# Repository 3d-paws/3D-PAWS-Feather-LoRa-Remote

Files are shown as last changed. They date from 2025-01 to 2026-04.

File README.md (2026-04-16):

# 3D-PAWS-Feather-LoRa-Remote

Last Updated: 2025-10-08

## Description

This software is supported on a Adafruit Feather LoRa board. It provides full weather station features. It uses LoRa (not LoRaWAN) to transmit observations to a receiving station for relay. Currently that is a Particle Full Station with Adafruit LoRa RFM95 module. Future plan is to also support for a RaspberryPI as a receiver and relay.

### Normal Main Loop operation
Normally the unit is in low power sleep mode. If a rain tip occurs, we wake up increment the tip count in the interrupt handler. Wakeup from sleep occures on configation settings of (5,6,10,15,20,30 minute) hourly periods. Actually wakeup is 1 minute prior from one of these periods. If Wind, Distance or Air Quality is configured. This allows time for samples to be taken for those observations where it is required. After observations have been made, they are transmitted in one or more LoRa messages. Then time to next observation is determined and we go into low power mode for this duration.

#### Things to Note

- The same sensors the Particle Full Station supports are supported by the Feather LoRaRemote. See [Particle Full Station Documentation](https://github.com/3d-paws/3D-PAWS-Particle-FullStation/blob/master/README.md) for sensors information.
- LoRa transmission are AES128 bit encrypted. The settings must match those on the receiving site.
- When we transmit we are sending to a LoRa gateway id 1. The receiving site must be addressed with the same id.
- Our LoRa id is set to match the Chords site these observations are destined for. The webhook at on the Particle Console will use this id to direct the observation to the logging site.
- Observation data are transmitted in JSON format. In that a unique device is is transmitted with every transmission. Example "devid":"548fa41ef43ee791". This can used if Chords is no longer the end logging site.
- At startup and every 24 hours after a INFO message is sent. These will be multiple LoRa messages. This is do to the LoRa message length constraint. INFO provides information on the station's configuration. File INFO.TXT on the SD card will be maintained with the most current information. Below is an example.

<div style="overflow:auto; white-space:pre; font-family: monospace; font-size: 8px; line-height: 1.5; height: 100px; border: 1px solid black; padding: 10px;">

```
{"at":"2026-04-13T15:58:08","id":2,"devid":"548fa41ef43ee791","mtype":"IF","ver":"FLR-260412","bv":4.28,"hth":1,"obsi":"15m","obsti":"15m","t2nt":"52s","elev":0,"rtro":"0:00","lora":"72,23,915MHz,OK","devs":"eeprom,dsmux,sd,gps","gps":{"lat":40.096000,"lon":-105.088398,"alt":1560.100000,"sat":11,"hdop":1.000000,"on":0}"sensors":"BMX1(BMP390),BMX2(BMP280),MCP1,SHT45(44),SHT31(45),HDC302X(46),BMP581(47),AS5600,WS(A2),HI,WBT,WBGT WO/GLOBE"}
```

</div>

- A I2C mux is supported for multiple Tinovi Soil Moisture sensors.
- SDU Boot is supported after the first code install via USB port is performed. After which to install new code you can add file UPDATE.BIN on the SD card. UPDATE.BIN is removed as part up the update process.

### Air Quality Sensor PM25AQI
- Air Quality Sensor PM25AQI must be connected to mux port 7. And feather pin D6 must be connected to PM25AQI pin SET. This turns on and off the PM25AQI fan and laser. The mux is needed to isolate the PM25AQI's I2C channel. The PM25AQI hold the I2C buss when powered down. Interfering with other I2C devices.
- Air Quality Sensor PM25AQI should be powered by the 5V VBUS pin. We have seen issues multiple i2c devices and the AQS.
- Adding a Air Quality Sensor PM25AQI has added instability with random lockup during sample taking.

### LoRa Antenna Length
The recommended antenna wire lengths for Adafruit LoRa Feather boards are frequency-dependent quarter-wave whip antennas:
- For 433 MHz, the antenna length should be 6.5 inches (16.5 cm).
- For 868 MHz, the antenna length should be 3.25 inches (8.2 cm).
- For 915 MHz, the antenna length should be 3 inches (7.8 cm).

## READMEs
### [Configuration File Example](docs/Configuration.md)
### [GPS Module](docs/GPSModule.md)
### [Pin Mappings](docs/PinMappings.md)

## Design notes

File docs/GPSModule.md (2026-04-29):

# GPS Module
[←Top](../README.md)<BR>
## Obtaining Time
A GPS module can be added but not necessary. If partnered with a Feather M0 LoRa board, The GPS will be used to set the RTC clock at power on Which means you do not need to enter a date and time on the the serial console to set the RTC.

Every 4 hours from power on, the RTC clock is updated from GPS.

Information (INFO) messages will contain geolocation information from the GPS.

## Use the below GPS module
- [Adafruit Mini GPS PA1010D - UART and I2C - STEMMA QT](https://www.adafruit.com/product/4415)

## Wiring
The GPS module connects to the i2c buss. A command will put the GPS to sleep. A pulse to the GPS's Reset  pin is required to wake the GPS up.  Connect the GPS Reset pin to the Feather D5 pin.

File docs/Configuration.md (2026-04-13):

# Configuration File Example
[←Top](../README.md)

On the SD card, create a file named CONFIG.TXT.

<div style="overflow:auto; white-space:pre; font-family: monospace; font-size: 8px; line-height: 1.5; height: 480px; border: 1px solid black; padding: 10px;">

```
#
# CONFIG.TXT
#
# Line Length is limited to 63 characters
#12345678901234567890123456789012345678901234567890123456789012

# Private Key - 128 bits (16 bytes of ASCII characters)
aes_pkey=10FE2D3C4B5A6978

# Initialization Vector must be and always will be 128 bits (16 bytes.)
# The real iv is actually myiv repeated twice
# 1234567 -> 0x12D687 = 0x00 0x12 0xD6 0x87 0x00 0x12 0xD6 0x87 
aes_myiv=1234567

# This unit's LoRa ID for Receiving and Sending Messages
# Also Chords Site instrument_id
lora_unitid=2

# LoRa Address who we are sending to aka LoRa 3D-PAWS
lora_gwid=1

# You can set transmitter power from 5 to 23 dBm, default is 13
lora_txpower=23

# Valid entries are 433, 866, 915
lora_freq=915

#################################################
# General Configurations Settings
#################################################
# No Wind Anemometer pin A2
# 0 = wind data
# 1 = no wind data
nowind=0

# Rain Gauge rg1 pin A3
# Options 0,1
# 0 = false
# 1 = true
rg1_enable=0

# OptionPin 1 - pin A4
# 0 = No sensor
# 1 = raw (op1r - average 5 samples spaced 10ms)
# 2 = 2nd rain gauge (rg2)
# 5 = 5m distance sensor (ds, dsr)
# 10 = 10m distance sensor (ds, dsr)
op1=0

# OptionPin 2 - pin A5
# 0 = No sensor (Pin in use if pm25aqi air quality detected)
# 1 = raw (op2r - average 5 samples spaced 10ms)
# 2 = read Voltaic battery voltage (vbv)
op2=0

# OptionPin 3 - pin A0
# 0 = No sensor
# 1 = raw (op3r - average 5 samples spaced 10ms)

# OptionPin 4 - pin A1
# 0 = No sensor
# 1 = raw (op4r - average 5 samples spaced 10ms)

# Distance sensor baseline. If positive, distance = baseline - ds_median
ds_baseline=0

# elevation used for MSLP
elevation=0

# Rain Total Rollover Offset from 0 UTC
# Set rtro to the UTC hour when your Rain Total Rollover action should occur.
#
# - Find your UTC offset (e.g., Denver MDT = -6, Kenya = +3)
# - Calculate: RTRO = Local_Hour - UTC_Offset
# - Use 0-23 range (if negative, add 24)
#
# Example: Set roll over to be at Midnight local time. 
# - Denver midnight MDT: 0 - (-6) = 6 
# - Kenya 6 AM:          6 - 3 = 3 
# - Sydney 8 AM AEDT:    8 - 11 = -3 + 24 = 21 
# - UTC midnight:        0 - 0 = 0
#
# rtro=H(:MM) - valid values are where H = (0-23) with optional ":" and MM = (00,15,30,45)
rtro=0

#################################################
# System Timing
#################################################

# Valid Observation Period in minutes (5,6,10,15,20,30)
# 15 minute observation period is the default
obs_period=15
```

</div>

### At initialization:
- I2C sensors are auto detected.

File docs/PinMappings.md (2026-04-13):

# Pin Mappings
[←Top](../README.md)<BR>

## Pin Definitions Table

| Board Label | Arduino | Info & Usage | Grove Shield Connector |
|---|---|---|---|
| RST | | | |
| 3V | 3v3 | Power | |
| ARef | | | |
| GND | | | |
| A0 | A0 | Option Pin 3 | Grove A0 |
| A1 | A1 | Option Pin 4 | Grove A0 |
| A2 | A2 | Interrupt for Anemometer | Grove A2 |
| A3 | A3 | Interrupt for Rain Gauge 1 | Grove A2 |
| A4 | A4 | Option Pin1 (op1) | Grove A4 |
| A5 | A5 | Option Pin2 (op2) | Grove A4 |
| SCK | SCK | SPI0 Clock - SD/LoRa | Not on Grove |
| MOS | MOSI | Used by SD Card/LoRa | Not on Grove |
| MIS | MISO | Used by SD Card/LoRa | Not on Grove |
| RX0 | D0 | | Grove UART |
| TX1 | D1 | | Grove UART |
| io1 | DIO1 | Do not use | Not on Grove (Particle Pin D9) |
| BAT | VBAT | Power | |
| En | | Connect to GND to disable 3.3V regulator | |
| USB | VBUS | Power | |
| 13 | D13 | LED | Not on Grove |
| 12 | D12 | Serial Console Enable | Not on Grove |
| 11 | D11 | Unused | Not on Grove |
| 10 | D10 | Used by SD Card as CS | Grove D4 (Particle Pin D5) |
| 9 | D9/A7 | Voltage Battery Pin | Grove D4 (Particle Pin D4) |
| 6 | D6 | to AQS Set Pin | Grove D2 (Particle Pin D3) |
| 5 | D5 | to GPS Rst Pin | Grove D2 (Particle Pin D2) |
| SCL | D3 | I2C Clock | Grove I2C_1 |
| SDA | D2 | I2C Data | Grove I2C_1 |

## Additional Pin Notes

**Not exposed on headers:**
- D8 = LoRa NSS (Chip Select CS)
- D4 = LoRa Reset  
- D3 = LoRa DIO

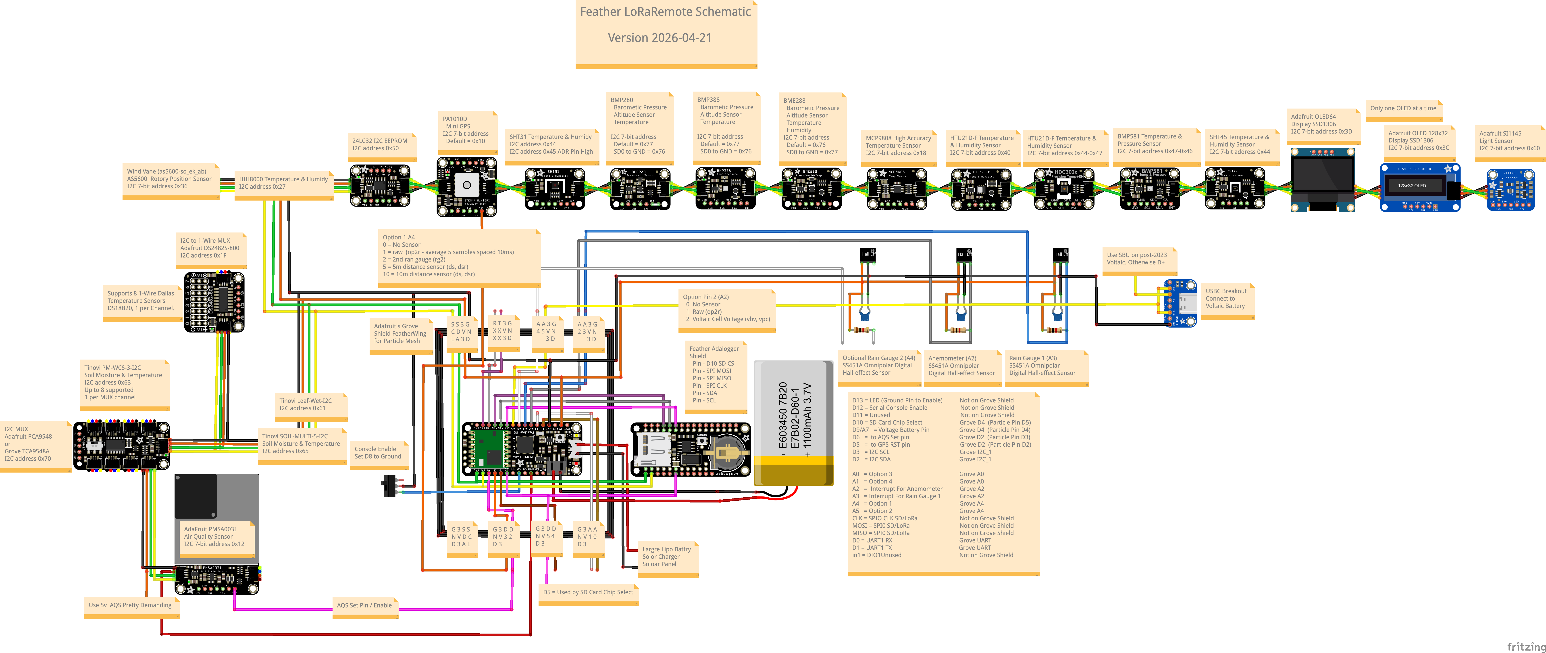
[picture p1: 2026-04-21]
Fritzing/FeatherLoRaRemote_v20260421.png

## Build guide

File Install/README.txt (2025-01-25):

Install Instructions

Exit Arduino Serial Monitor if it is running

Push the reset button twice quickly on the Feather board to set firmware download mode.
   The red LED by the battery connector will pulse quickly.
   COM port will change when in firmware download mode. 

Run install.bat

   Windows Defender may prevent the install.bat from running. 
      Open the properties of the install.bat file and see if there is a "unblock" check box. If so, select it.
                  
   Enter the COM port. - More COM information can be found with Device Manager
   Wait. A lot of read/write messages will scroll then you will see percentage download information

Exit the script

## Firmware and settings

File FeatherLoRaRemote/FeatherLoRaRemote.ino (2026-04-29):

#define COPYRIGHT "Copyright [2026] [University Corporation for Atmospheric Research]"
#define VERSION_INFO "FLR-260416"
/*
 *======================================================================================================================
 * FeatherLoRaRemote - 3D-PAWS-Feather-LoRaRemote
 *   Board Type : Adafruit Feather M0  #if defined(ADAFRUIT_FEATHER_M0)
 *   Description: Uses LoRa to report to Particle Full Stations for relay of observations 
 *   Author: Robert Bubon
 *   Date:   2025-01-15 RJB Renamed RS_LoRa_MO code base to LoRaRemoteM0
 *                          Reworked LoRa transmission format. Now sending JSON
 *                          Added INFO message at power on
 *                          Added cf_rg_disable to the config file for enable disable rain gauge option
 *                          Added support for Distance sensor on pin A4
 *           2025-01-23 RJB Added ds_basline to config file, If positive, distance = baseline - ds_median
 *                          Added support for observation intervals 5,6,10,15,20,30
 *                          Added support for Tinovi moisture sensors (Leaf, Soil, Multi Level Soil)                          
 *           2025-02-24 RJB Changes to Config File handing. Safty checks added.
 *           2025-03-09 RJB Replaced a direct Serial output in SDC.h SD_findKey() with Output() 
 *           2025-04-24 RJB Corrected bugs in negative temperature reporting
 *           2025-08-12 RJB Bug - Double incrementing SendMsgCount. Fixed in OBS.h
 *           2025-08-17 RJB added to INFO and OBS messages \"type\":\"IF\"  \"type\":\"OBS\"
 *           2025-09-11 RJB In OBS fixed casting bug on rain collection. Added (float)
 *                          (rain > (((float) rgds / 60) * QC_MAX_RG))
 *                          Fixed sending -999.-90 QC error values FIX (rain < 0 ? -rain : rain) added
 *           2025-09-16 RJB Added MUX support for Multiple Tinovi Capacitive Soil Moisture & Temperature sensors                         
 *                          Only wait for serial consile connection for 30 not 60 seconds. When jumper set
 *                          Only stay in station monitor for 5 minues not 30.
 *                          Adding Wind. If we detect the AS5600 Wind direction we will then wake up
 *                          take one minute of samples for wind, transmit and go back to sleep.
 *                          Added air quality, average of 10 1s samples. Must be on mux channel 7 with no other sensors.
 *           2025-09-20 RJB Added SDU support - Modified 
 *                          ~/Library/Arduino15/packages/adafruit/hardware/samd/1.7.16/libraries/SDU/src/SDU.cpp
 *                            #elif defined(ADAFRUIT_FEATHER_M0)
 *                            #include "boot/adafeatherM0.h"
 *                            Added adafeatherM0.h
 *           2025-09-23 RJB Fixed checksum error on LoRa INFO messages
 *                          Added the chunking of the observers into multiple lora packets
 *           2025-10-05 RJB Code clean up, True .h files with corresponding.cpp files.          
 *                          Added mux_deselect_all() and changed all mux_channel_set(0) to this
 *                          Added void LoRaDisableSPI() used in CF.cpp
 *                          Added LoRaSleep() use in loop()
 *           2025-10-08 RJB Bug fixes on INFO messages.
 *           2025-10-17 RJB Bug fix on MUX TSM initization of tsm_id.
 *           2025-10-26 RJB Removed unused variable in mux.h and mux.cpp
 *           2026-03-26 RJB Added DSMUX 1-Wire support for 8 temperature sensors dst0-7
 *                          Added cf_nowind
 *                          Clean up SSBits.
 *                          Bug fix on wind speed, Added Enable/Disable interrupt before/after the 60 samples
 *                          Added pinmode INPUT to wind rain
 *                          Removed the support for Tinovi MultiLevel Soil Moisture (4 Soil and 2 Temperature) 
 *                          Bug fix in statmon.cpp BMX identification
 *                          Added rtro range changed to 0-23 :00,15,30,45 
 *                          Add elevation for mslp
 *                          We now check if its time to roll rain total over before going back to sleep.
 *           2026-03-29 RJB Added volatile to interrupt routine variable definations
 *                          Change pin use (A0,A1) over to OP1 and OP2 and remove soil 1-wire temp and moisture
 *                          Add Voltaic
 *                          Add BMP581 and SMT45 - rework the i2c 0x44 - 0x47 sensore handling
 *                          Disabled interrupts when reading and setting shared values with the ISRs
 *                          Created functions to obtain rg1 and rg2 values
 *                          Modified rain ISR to only call millis() once.
 *                          It is possible for the RTC PCF8523 or its library to give you a month value of 0 added check.
 *                          Add GPS support for Time set, location reporting in INFO and low power mode when not using
 *                          Removed support for VMEL7700 Lux sensor address 0x10 collides with GPS
 *                          Change from Serial to Output("DSMUX:Select CH Err");
 *                          Changed SendAESLoraWanMsg to SendLoraAESMsg plus len check add
 *                          Changed GetDeviceID() to be a length of 16 instead of 24
 *           2026-04-12 RJB Code clean up on BMX processing in OBS and Station monitor, utilizing BMX_1_type from initializtion
 *                          Code clean up switch to %.2f on sprintf 
 *           2026-04-16 RJB Corrections on handling sht1_humid and sht1_temp for derived observations
 *           2026-04-29 RJB Correction in Wind_SampleSpeed() on delta_ms.
 * 
 * Time Format: 2022:09:19:19:10:00  YYYY:MM:DD:HR:MN:SS  Enter UTC time and not local time.
 * 
 * ======================================================================================================================
 * Normal loop operation
 * 
 * If a tip occurs we wake up from low power sleep and increment the tip count in the interrupt handler.
 * Upon wake up the code starts executing after the function "LowPower.sleep(GoToSleepTime);" in the loop() function.
 * The loop() function determines if the full sleep (15min) has transpired.
 *   If so,  an observation is made and transmitted. After, another 15min low sleep period occurs.
 *   If not, it calculates the amount of time left in the 15 minute sleep period.
 *      If this amount of time is 2s or less before next observation,it delays and avoids the sleep.
 *      Otherwise it enters low power sleep for the calculated amount of time.
 * As a result of the above, rain and all other observations have a granularity of 15 minutes
 * ======================================================================================================================
 *                    
 * SEE https://learn.adafruit.com/adafruit-feather-m0-radio-with-lora-radio-module
 * SEE https://learn.adafruit.com/assets/46254 for Pinouts      
 * SEE https://www.microchip.com/wwwproducts/en/ATsamd21g18
 * SEE https://learn.adafruit.com/adafruit-adalogger-featherwing/pinouts
 * SEE https://www.microchip.com/wwwproducts/en/MCP73831 - Battery Charger
 * 
 * Antenna Options - Wire 3in long for 915Mhz
 * https://learn.adafruit.com/adafruit-feather-m0-radio-with-lora-radio-module/antenna-options
 * https://www.changpuak.ch/electronics/bi_quad_antenna_designer.php
 * 
 * Arduino Low Power
 * SEE: https://www.arduino.cc/en/Reference/ArduinoLowPower
 * SEE https://github.com/arduino-libraries/ArduinoLowPower
 *  
 * Arduino/libraries/AES-master/AES_config.h  Modified to fix below problem.
 *     Arduino/libraries/AES-master/AES_config.h:43:18: fatal error: pgmspace.h: No such file or directory
 *     #include <pgmspace.h>
 *                ^~~~~~~~~~~~
 * diff AES_config.h.org AES_config.h
 *     40c40
 *     <     #if (defined(__AVR__))
 *     ---
 *     >     #if (true || defined(__AVR__))
 *     41a42
 *     >  #define printf_P printf
 * 
 * Compiling Note:
 * If you were prior compiling for the MKR NB 1500, change the board type to Feather M0 and swap out the 
 * Arduino/libraries/RF9X-RK-SPI1 library to the RF9X-RK
 * ======================================================================================================================
 * Pin Definitions
 * 
 * Board Label   Arduino  Info & Usage                   Grove Shield Connector   
 * ======================================================================================================================
 * RST
 * 3V            3v3 Power
 * ARef
 * GND
 * A0            A0       Option Pin 3                   Grove A0
 * A1            A1       Option Pin 4                   Grove A0
 * A2            A2       Interrupt For Anemometer       Grove A2
 * A3            A3       Interrupt For Rain Gauge 1     Grove A2
 * A4            A4       Option Pin 1                   Grove A4
 * A5            A5       Option Pin 2                   Grove A4
 * SCK           SCK      SPI0 Clock - SD/LoRa           Not on Grove
 * MOS           MOSI     Used by SD Card/LoRa           Not on Grove
 * MIS           MISO     Used by SDCard/LoRa            Not on Grove
 * RX0           D0                                      Grove UART
 * TX1           D1                                      Grove UART 
 * io1           DIO1     to D6 if LoRa WAN              Not on Grove (Particle Pin D9) !!!! Removed for LoRaRemote
   
 * BAT           VBAT Power
 * En            Control - Connect to ground to disable the 3.3v regulator
 * USB           VBUS Power
 * 13            D13      LED                            Not on Grove 
 * 12            D12      Serial Console Enable          Not on Grove
 * 11            D11      Unused                         Not on Grove
 * 10            D10      Used by SD Card as CS          Grove D4  (Particle Pin D5)
 * 9             D9/A7    Voltage Battery Pin            Grove D4  (Particle Pin D4)
 * 6             D6       AQS Set   pin                  Grove D2  (Particle Pin D3)
 * 5             D5       GPS Reset Pin                  Grove D2  (Particle Pin D2)
 * SCL           D3       i2c Clock                      Grove I2C_1
 * SDA           D2       i2c Data                       Grove I2C_1
 * 
 * Not exposed on headers
 * D8 = LoRa NSS aka Chip Select CS
 * D4 = LoRa Reset
 * D3 = LoRa DIO
 * ======================================================================================================================
 * Normal main loop operation
 * 
 * If a tip occurs we wake up increment the tip count in the interrupt handler.
 * Upon wake up the code starts executing after the function "LowPower.sleep(GoToSleepTime);" in the main loop.
 * The main loop determines if the full sleep period (5,6,10,15,20,30 min) has transpired.
 *   If so,  an observation is made and transmitted. After another 15min sleep period occurs.
 *   If not, It calculates the amount of time left in the 15 minute sleep period.
 *      If This amount of time is 2s or less before next observation,it delays and avoids the sleep.
 *      Otherwise it enters ultra low power sleep for the calculated amount of time.
 * So rain observations have a granularity of 15 minutes
 * ======================================================================================================================
 */

/*
 * Required Libraries:
 *  adafruit-HTU21DF        https://github.com/adafruit/Adafruit_HTU21DF_Library - I2C ADDRESS 0x40
 *  adafruit-BusIO          https://github.com/adafruit/Adafruit_BusIO 
 *  Adafruit_MCP9808        https://github.com/adafruit/Adafruit_MCP9808_Library - I2C ADDRESS 0x18
 *  Adafruit_BME280         https://github.com/adafruit/Adafruit_BME280_Library  - I2C ADDRESS 0x77  (SD0 to GND = 0x76)
 *  Adafruit_BMP280         https://github.com/adafruit/Adafruit_BMP280_Library  - I2C ADDRESS 0x77  (SD0 to GND = 0x76)
 *  Adafruit_BMP3XX         https://github.com/adafruit/Adafruit_BMP3XX          - I2C ADDRESS 0x77 and (SD0 to GND = 0x76)
 *  Adafruit_BMP5xx         https://github.com/adafruit/Adafruit_BMP5xx          - I2C ADDRESS 0x47 and 0x47
 *  Adafruit_GFX            https://github.com/adafruit/Adafruit-GFX-Library
 *  Adafruit_Sensor         https://github.com/adafruit/Adafruit_Sensor
 *  Adafruit_SHT31          https://github.com/adafruit/Adafruit_SHT31           - I2C ADDRESS 0x44 and 0x45 when ADR Pin High
 *  Adafruit_SHT4x          https://github.com/adafruit/Adafruit_SHT4x           - I2C ADDRESS 0x44
 *  Adafruit_VEML7700       https://github.com/adafruit/Adafruit_VEML7700        - I2C ADDRESS 0x10
 *  Adafruit_SI1145         https://github.com/adafruit/Adafruit_SI1145_Library  - I2C ADDRESS 0x60
 *  Adafruit_SSD1306        https://github.com/adafruit/Adafruit_SSD1306         - I2C ADDRESS 0x3C  
 *  Adafruit_PM25AQI        https://github.com/adafruit/Adafruit_PM25AQI         - I2C ADDRESS 0x12 - Modified to Compile, Adafruit_PM25AQI.cpp" line 104
 *  RTCLibrary              https://github.com/adafruit/RTClib
 *  SdFat                   https://github.com/greiman/SdFat.git - 1.0.16 by Bill Greiman
 *  RF9X-RK-SPI1            https://github.com/rickkas7/AdafruitDataLoggerRK - 0.2.0 - Modified RadioHead LoRa for SPI1
 *  AES-master              https://github.com/spaniakos/AES - 0.0.1 - Modified to make it compile
 *  CryptoLW-RK             https://github.com/rickkas7/CryptoLW-RK - 0.2.0
 *  HIH8000                 No Library, Local functions hih8_initialize(), hih8_getTempHumid() - rjb
 *  SENS0390                https://wiki.dfrobot.com/Ambient_Light_Sensor_0_200klx_SKU_SEN0390 - DFRobot_B_LUX_V30B - 1.0.1 I2C ADDRESS 0x94
 *  EEPROM                  https://docs.particle.io/reference/device-os/api/eeprom/eeprom/ , https://www.adafruit.com/product/5146
 *  SpatkFun_I2C_GPS        https://github.com/sparkfun/SparkFun_I2C_GPS_Arduino_Library I2C ADDRESS 0x10
 *  LeafSens                https://github.com/tinovi/LeafArduinoI2c I2C ADDRESS 0x61
 *  i2cArduino              https://github.com/tinovi/i2cArduino     I2C ADDRESS 0x63
 */

/*
 * ======================================================================================================================
 * Add SDUBoot Support for UPDATE.BIN on SD card
 * ======================================================================================================================
 */
#include "boot/SDU.h"

/* 
 *=======================================================================================================================
 * Includes
 *=======================================================================================================================
 */
#include <ArduinoLowPower.h>

#include "include/ssbits.h"
#include "include/feather.h"
#include "include/mux.h"
#include "include/qc.h"
#include "include/eeprom.h"
#include "include/obs.h"
#include "include/wrda.h"
#include "include/cf.h"
#include "include/sdcard.h"
#include "include/info.h"
#include "include/dsmux.h"
#include "include/sensors_i2c_44_47.h"
#include "include/sensors.h"
#include "include/output.h"
#include "include/lora.h"
#include "include/statmon.h"
#include "include/support.h"
#include "include/gps.h"
#include "include/time.h"
#include "include/main.h"

/*
 * ======================================================================================================================
 * Variables and Data Structures 
 * =======================================================================================================================
 */
bool JustPoweredOn = true;   // Used to clear SystemStatusBits set during power on device discovery

char versioninfo[sizeof(VERSION_INFO)];  // allocate enough space including null terminator
char msgbuf[MAX_MSGBUF_SIZE];// Buffer used all over the code
char *msgp;                  // Pointer used all over the code
char Buffer32Bytes[32];      // Buffer used all over the code

// Local
int countdown = 300;      // Exit calibration mode when reaches 0 - protects against burnt out pin or forgotten jumper
unsigned long nextTimeRefresh=0; // Time of Next Time refresh
unsigned long nextinfo=0; // Time of Next INFO transmit


void sleepinterrupt() {
  Output("I");
}
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
void loop()
{
  static time_t sleep_time = 0;
  time_t time_asleep;
  int GoToSleepTime;

  rtc_timestamp(); // get time from rtc, update datetime structure "now", and update timestamp string
  
  // RTC not set, Get Time for User
  if (!RTC_valid) {
    static bool first = true;

    delay (1000);
      
    if (first) {
      // Enable Serial if not already
      if (digitalRead(SCE_PIN) != LOW) {
        Serial.begin(9600);
        delay(2000);
        SerialConsoleEnabled = true;
      }  
    
      // Show invalid time and prompt for UTC Time
      Output(timestamp);
      Output(F("SET RTC w/GMT, ENTER:"));
      Output("YYYY:MM:DD:HH:MM:SS");
      first = false;
    }
    
    // Core Loop start looking for time
    // Two things can happen. User enters valid time or we get time from GPS
    rtc_readserial(); // check for serial input, validate for rtc, set rtc, report result

    if (!RTC_valid) {
      rtc_refresh(); // Get time from GPS
    }
    // Core Loop End looking for time

    if (RTC_valid) {
      Output(F("!!!!!!!!!!!!!!!!!"));
      Output(F("!!! Rebooting !!!"));
      Output(F("!!!!!!!!!!!!!!!!!")); 
      delay(2000);
      SystemReset(); // We don't use the watchdog to reboot. So soft reset to keep GPS and RTC powered.
    }
  }

  //Calibration mode, You can also reset the RTC here
  else if (countdown && digitalRead(SCE_PIN) == LOW) { 
    StationMonitor();
    
    // check for input sting, validate for rtc, set rtc, report result
    if (Serial.available() > 0) {
      rtc_readserial(); // check for serial input, validate for rtc, set rtc, report result
    }
    
    countdown--;
    delay (1000);
  }

  // Normal Operation
  else {
    // Delayed initialization. We need a valid clock before we can validate the EEPROM
    if (eeprom_exists && !eeprom_valid) {
      EEPROM_Validate();
      EEPROM_Dump();
      SD_ClearRainTotals(); 
    }
        
    // Every 24 hours send INFO
    
    if (now.unixtime() > nextinfo) {      // Upon power on this will be true
      INFO_Do();
      nextinfo = now.unixtime() + (3600 * 24);      
    }

    // Upon power on this will be true
    // Upon no rain and time has moved pasted the wakeuptime this will be true
    // If there was a rain tip and time is less than the wakeuptime but time is after the rollover time, this will be true
    // Aka on each rain tip we check to see if we need to rollover the daily total.
    if ((now.unixtime() >= wakeuptime) || EEPROM_TimeToRollOver()) { 
      OBS_Do();

      // Shutoff System Status Bits related to initialization after we have logged first observation
      JPO_ClearBits();
    }

    // Update the RTC clock from GPS. 
    if (gps_exists) {
      if (gps_on || (millis() >= nextTimeRefresh)) {
        if (rtc_refresh()) {
          // Time should be set and gps should be off, lets get a gps time update in N hours.
          nextTimeRefresh = millis() + (3600 * RTC_UPDATE_INTERVAL) * 1000;
        }
        else {
          // GPS was left on, so lets try again in 5 minutes or the next time we wake up.
          nextTimeRefresh = millis() + (5 * 60) * 1000;
        }
      }
      if (!gps_on) {
        // Seem like the GPS sneaks on from time to time, when we have gps_on set to false. So lets make sure it stays off.
        gps_keepoff(); // This will also call gps_aquire(); Which shuts it down.
      }
    }

    unsigned long stno = seconds_to_next_obs();
      
    if (stno <= 2) {
      // Avoid going to sleep if there is 2s or less time until we need to do an observation
      // This is really here to address going into low power move for a fraction of a second.
      Output("Delay - Not Sleep");
      delay (GoToSleepTime);
    }
    else {  
      sprintf (Buffer32Bytes, "Sleep for %us", stno);
      Output (Buffer32Bytes);  

      LoRaSleep();
    
      OLED_sleepDisplay();

      wakeuptime = stno + now.unixtime(); // "now" was updated in the seconds_to_next_obs() function
      LowPower.sleep(stno*1000); // uses milliseconds
 
      OLED_wakeDisplay();   // May need to toggle the Display reset pin.
      delay(2000);
      OLED_ClearDisplayBuffer(); 
      Output("Wakeup");
    }
  } // End Normal Operation
}

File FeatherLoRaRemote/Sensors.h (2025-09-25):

/*
 * ======================================================================================================================
 *  Sensors.h
 * ======================================================================================================================
 */

/*
 * ======================================================================================================================
 *  BMX280 humidity - I2C - Temperature, pressure sensor & altitude - Support 2 of any combination
 * 
 *  https://www.asknumbers.com/PressureConversion.aspx
 *  Pressure is returned in the SI units of Pascals. 100 Pascals = 1 hPa = 1 millibar. 
 *  Often times barometric pressure is reported in millibar or inches-mercury. 
 *  For future reference 1 pascal = 0.000295333727 inches of mercury, or 1 inch Hg = 3386.39 Pascal. 
 *
 *  Looks like you divide by 100 and you get millibars which matches NWS page
 * 
 *  Surface Observations and Station Elevation 
 *  https://forecast.weather.gov/product.php?issuedby=BOU&product=OSO&site=bou 
 * 
 * The Bosch BMPXXX sensors all have this issue of saving the last reading. 
 * The recommended solution is to always throw away the first reading after any long 
 * period of inactivity (sleep or power on).
 * SEE https://forums.adafruit.com/viewtopic.php?t=209906
 * ======================================================================================================================
 */
// #define BMX_STATION_ELEVATION 1017.272  // default 1013.25
#define BMX_ADDRESS_1         0x77      // BMP Default Address - Connecting SDO to GND will change BMP to 0x76
#define BMX_ADDRESS_2         0x76      // BME Default Address - Connecting SDO to GND will change BME to 0x77
#define BMP280_CHIP_ID        0x58
#define BME280_BMP390_CHIP_ID 0x60
#define BMP388_CHIP_ID        0x50
#define BMX_TYPE_UNKNOWN      0
#define BMX_TYPE_BMP280       1
#define BMX_TYPE_BME280       2
#define BMX_TYPE_BMP388       3
#define BMX_TYPE_BMP390       4
Adafruit_BMP280 bmp1;
Adafruit_BMP280 bmp2;
Adafruit_BME280 bme1;
Adafruit_BME280 bme2;
Adafruit_BMP3XX bm31;
Adafruit_BMP3XX bm32;
byte BMX_1_chip_id = 0x00;
byte BMX_2_chip_id = 0x00;
bool BMX_1_exists = false;
bool BMX_2_exists = false;
byte BMX_1_type=BMX_TYPE_UNKNOWN;
byte BMX_2_type=BMX_TYPE_UNKNOWN;
const char *bmxtype[] = {"UNKN", "BMP280", "BME280", "BMP388", "BMP390"};

/*
 * ======================================================================================================================
 *  HTU21D-F - I2C - Humidity & Temp Sensor
 * ======================================================================================================================
 */
Adafruit_HTU21DF htu = Adafruit_HTU21DF();
bool HTU21DF_exists = false;

/*
 * ======================================================================================================================
 *  MCP9808 - I2C - Temperature sensor
 * 
 * I2C Address is:  0011,A2,A1,A0
 *                  0011000 = 0x18  where A2,1,0 = 0 MCP9808_I2CADDR_DEFAULT  
 *                  0011001 = 0x19  where A0 = 1
 *                  0011001 = 0x1A  where A1 = 1
 *                  0011011 = 0x1B  where A0 & A1 = 1
 * ======================================================================================================================
 */
#define MCP_ADDRESS_1     0x18        // Default
#define MCP_ADDRESS_2     0x19        // A0 set high, VDD
#define MCP_ADDRESS_3     0x1A        // A1 set high, VDD
#define MCP_ADDRESS_4     0x1B        // A0 & A1 set high, VDD

Adafruit_MCP9808 mcp1;
Adafruit_MCP9808 mcp2;
Adafruit_MCP9808 mcp3;
Adafruit_MCP9808 mcp4;
bool MCP_1_exists = false;
bool MCP_2_exists = false;
bool MCP_3_exists = false;
bool MCP_4_exists = false;

/*
 * ======================================================================================================================
 *  SHTX - I2C - Temperature & Humidity sensor (SHT31)  - Note the SHT40, SHT45 use same i2c address
 * ======================================================================================================================
 */
#define SHT_ADDRESS_1     0x44
#define SHT_ADDRESS_2     0x45        // ADR pin set high, VDD
Adafruit_SHT31 sht1;
Adafruit_SHT31 sht2;
bool SHT_1_exists = false;
bool SHT_2_exists = false;

/*
 * ======================================================================================================================
 *  HIH8 - I2C - Temperature & Humidity sensor (HIH8000)  - 
 * ======================================================================================================================
 */
#define HIH8000_ADDRESS   0x27
bool HIH8_exists = false;

/*
 * ======================================================================================================================
 *  Wet Bulb Temperature - Derived from Temperature and Humidity Sensors
 * ======================================================================================================================
 */
bool WBT_exists = false;

/*
 * ======================================================================================================================
 *  Heat Index Temperature - Derived from Temperature and Humidity Sensors
 * ======================================================================================================================
 */
bool HI_exists = false;

/*
 * ======================================================================================================================
 *  Wet Bulb Globe Temperature - Derived from Temperature and Humidity Sensonrs
 * ======================================================================================================================
 */
bool WBGT_exists = false;

/*
 * ======================================================================================================================
 *  Si1145 - I2C - UV/IR/Visible Light Sensor
 *  The SI1145 has a fixed I2C address (0x60), you can only connect one sensor per microcontroller!
 * ======================================================================================================================
 */
Adafruit_SI1145 uv = Adafruit_SI1145();
bool SI1145_exists = false;
// When we do a read of all three and we get zeros. If these last readings are not zero, we will reinitialize the
// chip. When does a reset on it and then read again.
float si_last_vis = 0.0;
float si_last_ir = 0.0;
float si_last_uv = 0.0;

/*
 * ======================================================================================================================
 *  VEML7700 - I2C - Lux Sensor
 * ======================================================================================================================
 */
#define VEML7700_ADDRESS   0x10
Adafruit_VEML7700 veml = Adafruit_VEML7700();
bool VEML7700_exists = false;
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

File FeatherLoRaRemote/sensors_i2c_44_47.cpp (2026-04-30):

/*
 * ======================================================================================================================
 *  sensors_i2c_44_47.cpp - Discover I2C Sensors on addresses 0x44 to 0x47
 * ======================================================================================================================
 */
#include "include/qc.h"
#include "include/sensors.h"
#include "include/sensors_i2c_44_47.h"
#include "include/support.h"
#include "include/output.h"
#include "include/obs.h"
#include "include/main.h"

/*
 * ======================================================================================================================
 * Variables and Data Structures
 * =======================================================================================================================
 */
I2C_44_47_SENSOR_SLOT i2c_44_47_sensors[I2C_44_47_SENSOR_COUNT];

bool SHT_1_exists = false;
float sht1_humid = 0.0;
float sht1_temp = 0.0;



/*
 * ======================================================================================================================
 * Fuction Definations
 * =======================================================================================================================
 */

/*
 * ======================================================================================================================
 * readBytes()
 * =======================================================================================================================
 */
bool readBytes(uint8_t addr, uint8_t *buf, size_t len, uint16_t timeoutMs = 1000) {
  Wire.requestFrom(addr, (uint8_t)len);
  unsigned long start = millis();
  size_t i = 0;
  while (i < len && (millis() - start) < timeoutMs) {
    if (Wire.available()) {
      buf[i++] = Wire.read();
    }
  }
  return i == len;
}

/*
 * ======================================================================================================================
 * sht31_probe()
 * =======================================================================================================================
 */
bool sht31_probe(uint8_t addr) {
  Wire.beginTransmission(addr);
  Wire.write(0x37);
  Wire.write(0x80);
  if (Wire.endTransmission(false) != 0) return false;

  delay(1);

  uint8_t data[6];
  if (Wire.requestFrom(addr, (uint8_t)6) != 6) return false;

  for (int i = 0; i < 6; i++) data[i] = Wire.read();

  uint16_t sn1 = ((uint16_t)data[0] << 8) | data[1];
  uint16_t sn2 = ((uint16_t)data[3] << 8) | data[4];

  return (sn1 != 0x0000 || sn2 != 0x0000);
}

/*
 * ======================================================================================================================
 * sht45_probe()
 * =======================================================================================================================
 */
bool sht45_probe() {
  Adafruit_SHT4x sht4;
  return sht4.begin();
}

/*
 * ======================================================================================================================
 * bmp581_probe()
 * =======================================================================================================================
 */
bool bmp581_probe(uint8_t addr) {
  Wire.beginTransmission(addr);
  Wire.write(0x01);                    // CHIP_ID register = 0x50
  if (Wire.endTransmission(false) != 0) return false;

  if (Wire.requestFrom(addr, (uint8_t)1) != 1) return false;

  uint8_t chipid = Wire.read();
  return (chipid == 0x50);
}


/*
 * ======================================================================================================================
 * hdc302x_probe()
 * =======================================================================================================================
 */
bool hdc302x_probe(uint8_t addr) {
  Wire.beginTransmission(addr);
  Wire.write(0x37);
  Wire.write(0x81);
  if (Wire.endTransmission(false) != 0) return false;

  delay(20);

  uint8_t data[3];
  if (!readBytes(addr, data, 3)) return false;

  uint16_t manufacturer_id = ((uint16_t)data[0] << 8) | data[1];
  return (manufacturer_id == 0x3000);
}
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
